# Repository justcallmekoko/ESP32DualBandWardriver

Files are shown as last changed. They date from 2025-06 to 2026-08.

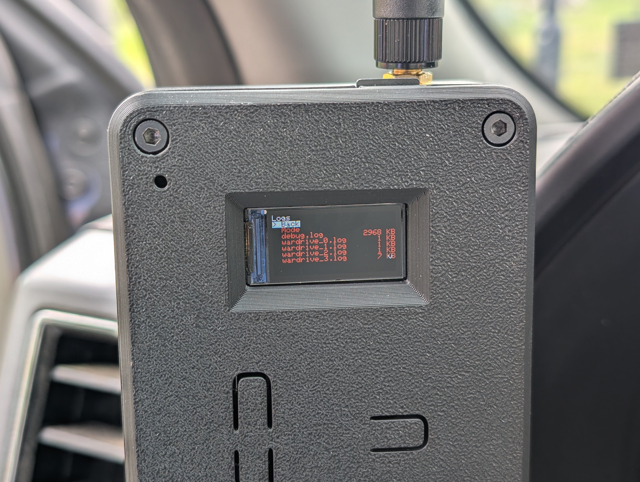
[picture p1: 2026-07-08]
docs/images/FileScreen.jpg

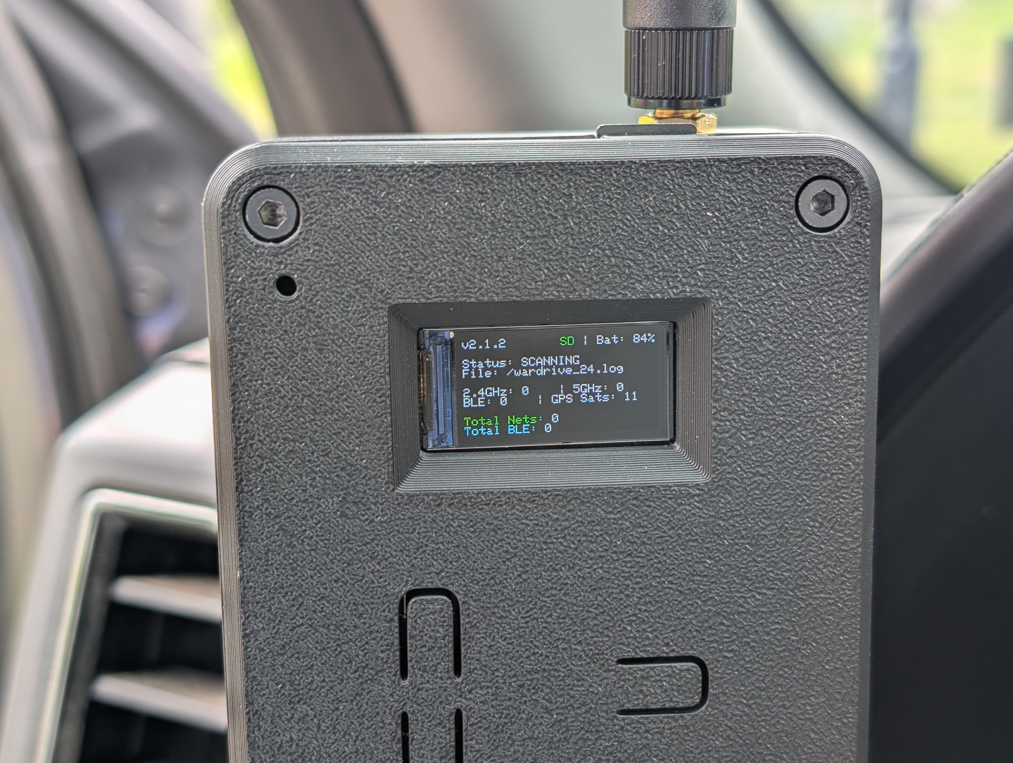
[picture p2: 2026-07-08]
docs/images/OriginalScreen2.jpg

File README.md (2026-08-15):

# ESP32 Dual Band Wardriver
Based on the ESP32-C5-DevKitC-1 v1.2, the ESP32 Dual Band Wardriver offers wardriving capabilities for 2.4GHz and 5GHz WiFi as well as BLE.
Logs are formatted for WiGLE and saved to SD card.

## Table of Contents
- [Leaderboards](#leaderboards)
- [Connections](#connections)
    - [Display](#display)
    - [GPS](#gps)
    - [SD Card](#sd-card)
    - [Battery Fuel Gauge](#battery-fuel-gauge)
    - [Activity LED](#activity-led)
    - [User Buttons](#user-buttons)
- [Install Firmware](#install-firmware)
- [Update Firmware](#update-firmware)
    - [Browser Installer (Recommended)](#browser-installer-recommended)
    - [SD Card Update](#sd-card-update)
- [Usage](#usage)
    - [Booting](#booting)
    - [Initial Setup](#initial-setup)
    - [Webserver Usage](#webserver-usage)
    - [Display Screens](#display-screens)
    - [Buttons](#buttons)
    - [Uploads](#uploads)
    - [Dock Mode](#dock-mode)
    - [Geofence Zones](#geofence-zones)
    - [SSID Exclusions](#ssid-exclusions)
    - [Debug Logging](#debug-logging)
- [Modes](#modes)

## Leaderboards
Join **#wardriving** on [WiGLE](https://wigle.net/stats#groupstats) and **KokosStripClub (invite code: _mN01r0TAS8q)** on [WDGWars](https://wdgwars.pl) to have a little competitive fun with the art of wardriving.

## Connections
**IMPORTANT: If you are using the ESP32-C5-DevKitC-1 with the JCMK C5 Wardriver host board or you are powering your DevKit via the 3V3 pin, you must remove the [3V3 jumper](https://docs.espressif.com/projects/esp-dev-kits/en/latest/esp32c5/esp32-c5-devkitc-1/user_guide.html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) from the DevKit or your device will not power properly.**

### [Display](https://a.co/d/dO8M3Ec)
| ESP32-C5 | Display |
| --- | --- |
| `3V3` | `VCC` |
| `GND` | `GND` |
| `GPIO6`  | `SCK` |
| `GPIO7`  | `MOSI`  |
| `GPIO23` | `CS` |
| `GPIO24` | `DC` |
| `GPIO27` | `BL` |
| `RST` | `RST` |

### [GPS](https://a.co/d/hIqIitg)
| ESP32-C5 | GPS |
| --- | ----- |
| `3V3` | `VCC` |
| `GND` | `GND` |
| `GPIO13` | `RX`  |
| `GPIO14` | `TX`  |

> **Tip:** The GPS module's ceramic patch antenna should be oriented face-up toward the sky for best signal. In the JCMK host board case the antenna mounts vertically by default — relocating it to the top of the enclosure significantly improves acquisition time.

### [SD Card](https://www.sparkfun.com/sparkfun-microsd-transflash-breakout.html)
| ESP32-C5 | SD |
| --- | --- |
| `3V3` | `VCC`  |
| `GND` | `GND`  |
| `GPIO6`  | `SCK`  |
| `GPIO2`  | `MISO` |
| `GPIO7`  | `MOSI` |
| `GPIO10` | `CS` |

### [Battery Fuel Gauge](https://www.adafruit.com/product/5580)
| Board | ESP32-C5 | Pin |
| --- | --- | ----- |
| | `GPIO4`  | `SCL` |
| | `GPIO5`  | `SDA` |
| | `3V3` | `VCC` |
| | `GND` | `GND` |
| `Battery +` | | `BAT` |

### Activity LED
| ESP32-C5 | LED |
| --- | --- |
| `GPIO28` | `+` |
| `GND` | `-` |

### User Buttons
The User Buttons require pull-down resistors.
| ESP32-C5 | Button |
| --- | --- |
| `GPIO8`  | `DOWN` |
| `GPIO9`  | `UP` |
| `GPIO15` | `SELECT` |

## Install Firmware

The [C5 Wardriver Installer](https://justcallmekoko.github.io/C5WardriverInstaller/) is the default and recommended method for installing firmware. It runs in a Chromium-based browser with Web Serial support, such as Google Chrome or Microsoft Edge.

1. Connect the ESP32-C5 DevKit to your computer with a USB data cable.
2. Open the [C5 Wardriver Installer](https://justcallmekoko.github.io/C5WardriverInstaller/).
3. Select the desired hardware and firmware version from the catalog.
4. Leave **Clean / first install** selected for a new device or a device previously running different firmware.
5. Read and acknowledge the erase warning, then select **Flash firmware** and choose the ESP32-C5 serial device.
6. Keep the device connected until the installer reports that flashing is complete, then power-cycle it.

**Clean / first install** erases the device and writes the complete compatible flash layout, including the bootloader, partition table, OTA data, and application. This is required when the existing flash layout is unknown or incompatible.

## Update Firmware

### Browser Installer (Recommended)

Use the [C5 Wardriver Installer](https://justcallmekoko.github.io/C5WardriverInstaller/) for normal firmware updates:

1. Connect the ESP32-C5 DevKit to your computer with a USB data cable.
2. Select the desired catalog firmware.
3. Select **Update / preserve settings** when the device already has a compatible C5 Wardriver flash layout.
4. Select **Flash firmware**, choose the ESP32-C5 serial device, and wait for completion before power-cycling.

Update mode preserves settings and writes the application to `app0` before updating OTA selection so the new firmware boots. If the device is factory-fresh, has an unknown partition layout, or does not boot after an update, repeat the process with **Clean / first install**.

### SD Card Update

SD card updates remain supported when a browser and direct USB connection are not convenient. The firmware checks the SD card root at every boot for a new `.bin` file and automatically installs it when found.

1. Download the latest firmware from [Releases](../../releases)
2. Place the `.bin` file on the root of your SD card
3. Install the SD card into the C5 Wardriver
4. Boot the C5 Wardriver and allow the automatic update process to execute

## Usage

### Booting
When powered on, the C5 Wardriver attempts to connect to WiFi using saved credentials. If no credentials are saved or the network is unavailable, it starts its own access point named `c5wardriver` (password: `c5wardriver`). The AP remains active for 60 seconds if no clients connect, or until all clients disconnect.

If the device connects to a saved WiFi network, the web UI remains available indefinitely — it will stay connected until the network disappears. You can skip the admin phase entirely by holding `SELECT` when the boot logo appears.

### Initial Setup
On first boot, connect to the `c5wardriver` access point and navigate to `http://192.168.4.1`. From the web UI you can configure:

- **WiFi SSID / Password** — network to connect at boot for web UI access
- **WiGLE API credentials** — for direct log upload to WiGLE
- **WDG Wars API key** — for direct log upload to WDGWars
- **Trigger SSID / Password** — network that triggers dock mode (see [Dock Mode](#dock-mode))
- **Admin Password** — enables Basic Auth on the web UI
- **SSID Exclusions** — SSIDs to never log
- **Geofence Zones** — zones where wardriving pauses
- **SD Debug Log** — enable to write all log entries to `/debug.log` on the SD card

### Webserver Usage
At every boot, if connected to a saved WiFi network, the device IP is shown on the display. Navigate to that IP from any device on the same network to access the web UI. From here you can download log files, upload to WiGLE or WDGWars, and reconfigure all settings.

A live log viewer is available at `http://<device-ip>/log` — auto-refreshes every 5 seconds and shows the last 100 log entries.

### Display Screens
Cycle between screens using the `UP` and `DOWN` buttons.

**Screen 1 — Stats (default)**
Large-format wardriving stats: GPS satellite count and lock status, battery percentage, scan status, current session 2.4GHz / 5GHz / BLE counts, running totals, and active geofence zone name.

**Screen 2 — Detail**
Original stats display: firmware version, SD status, battery, scan status, log file name, per-band counts, GPS satellites, and running totals.

**Screen 3 — Incognito**
5-second countdown then backlight off. Press any button to exit.

### Buttons
| Button | Function |
| --- | --- |
| `UP` | Cycle display mode forward |
| `DOWN` | Cycle display mode backward |
| `SELECT` | Hold at boot logo to skip admin phase |

### Uploads
Log files can be uploaded to WiGLE and WDGWars directly from the web UI or automatically via dock mode. Select a log file from the file list and choose Upload — options are WiGLE, WDGWars, or Both.

Sidecar files (`.wigle` / `.wdg`) are created after successful uploads to prevent duplicate uploads across reboots.

### Dock Mode
Dock mode automates log uploads when the wardriver detects a configured trigger SSID.

**How it works:**
1. While wardriving or in standby, the device passively scans for the trigger SSID every 30 seconds
2. When detected, it connects and uploads all pending log files (files without upload sidecars)
3. It monitors for the trigger SSID to disappear, then resumes wardriving automatically

**Two-tier operation:**
- **Tier 1 (no GPS fix):** Connects and serves the web UI only — no upload triggered
- **Tier 2 (GPS fix + SD card):** Full dock mode — uploads all pending logs to WiGLE and WDGWars

Tier 1 automatically upgrades to Tier 2 if a GPS fix is acquired while docked.

Configure the trigger SSID and password in the web UI under **Dock Mode**. The trigger SSID is separate from the boot WiFi network.

### Geofence Zones
Up to 5 geofence zones can be configured with a label, latitude/longitude, and radius (0.10 to 1.00 miles). When the wardriver enters a geofence zone, wardriving pauses and the zone name is shown on the display. Wardriving resumes automatically when the zone is exited.

Zones are configured from the web UI under **Geofences**.

### SSID Exclusions
Up to 10 SSIDs can be added to the exclusion list. Networks matching an excluded SSID are never logged regardless of location. Useful for filtering out your own networks or known networks you don't want to record.

Configure from the web UI under **SSID Exclusions**.

### Debug Logging
Enable **SD Debug Log** in the web UI Admin section to write all log entries to `/debug.log` on the SD card. Useful for diagnosing issues in the field without a serial connection. The debug log is available for download from the web UI file list but is excluded from upload queues.

## Modes
The C5 Wardriver supports multiple ESP32 modules operating as collection nodes reporting to a single Core device. Nodes and Cores communicate over-the-air within typical WiFi range.

**When configuring device mode from the web UI, the mode persists across reboots. When selecting mode from the on-device menu, it is temporary and resets on next boot.**

### Solo Mode
Standalone operation. Requires SD card, GPS module, and GPS fix. Logs directly to SD and supports direct upload to WiGLE and WDGWars.

### Node Mode
Collects wardriving data and sends it to a Core device. Does not require SD card or GPS.

### Core Mode
Receives data from Nodes, pairs it with GPS location data, and saves consolidated log files to SD. Requires SD card and GPS. Does not collect wardriving data itself. Supports direct upload to WiGLE and WDGWars.

### Encryption
Node-to-Core communications can be encrypted. Enable via the web UI. When encryption is enabled, a maximum of 6 nodes can operate simultaneously due to memory constraints. Without encryption, the number of nodes is theoretically unlimited.

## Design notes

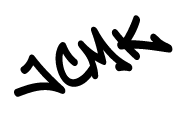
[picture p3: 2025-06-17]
images/jcmk.png

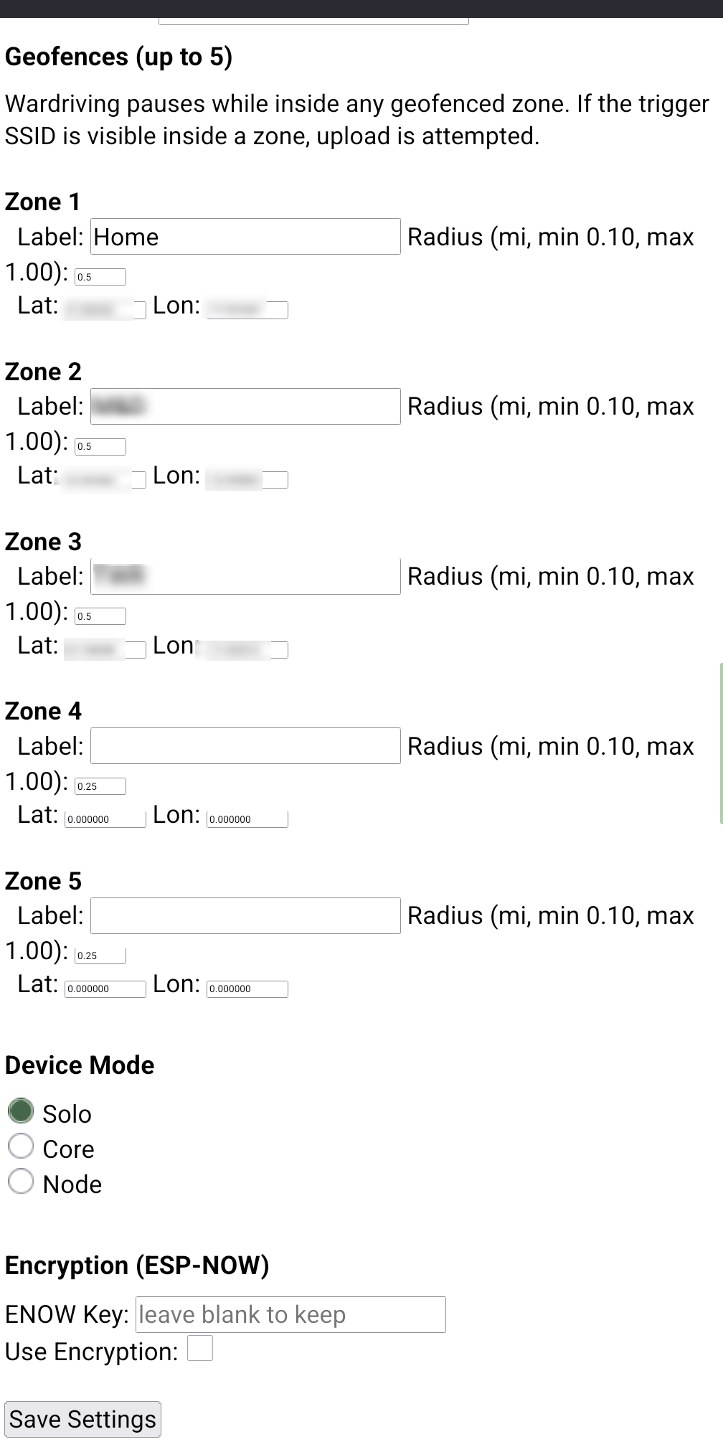
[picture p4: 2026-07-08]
docs/images/WebGeofenceScreen.png

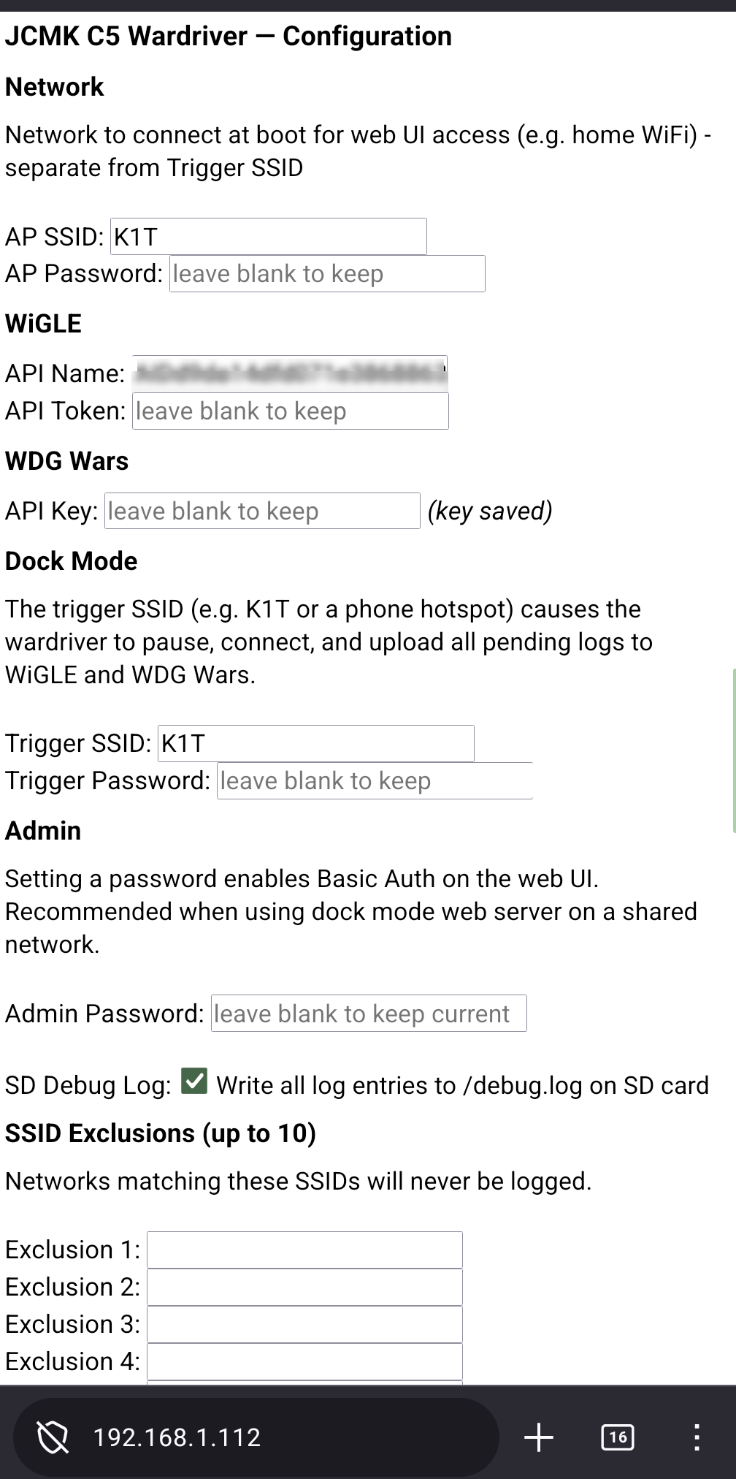
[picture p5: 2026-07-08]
docs/images/WebConfigScreen.png

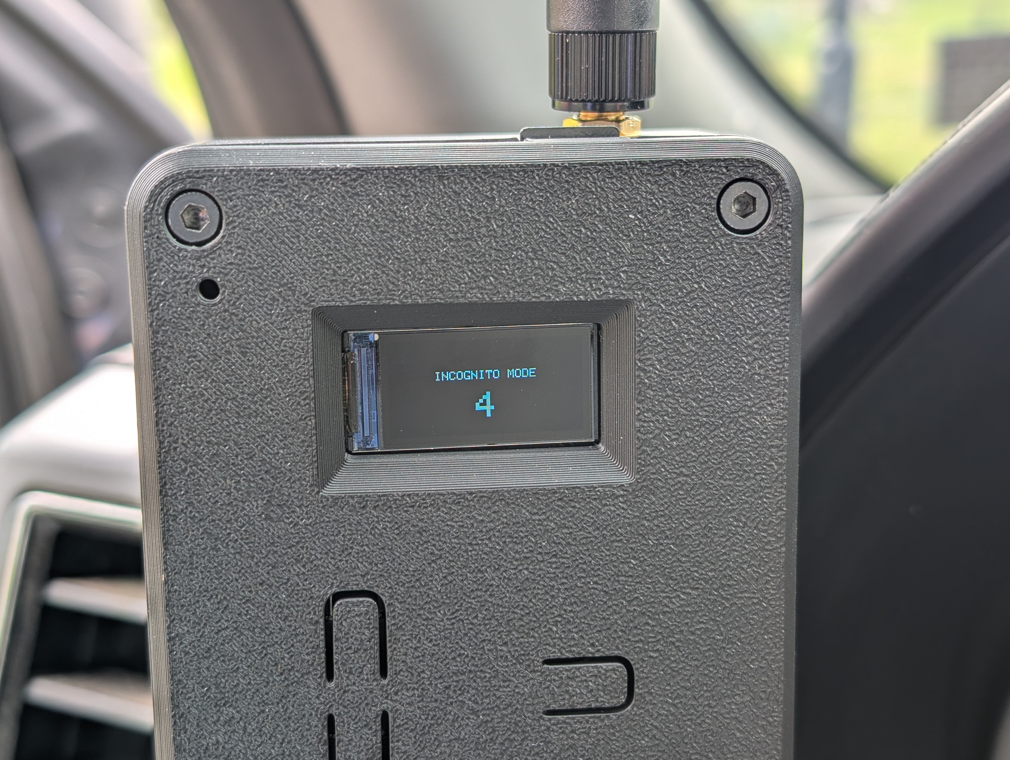
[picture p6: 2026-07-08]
docs/images/IgcognitoScreen.jpg

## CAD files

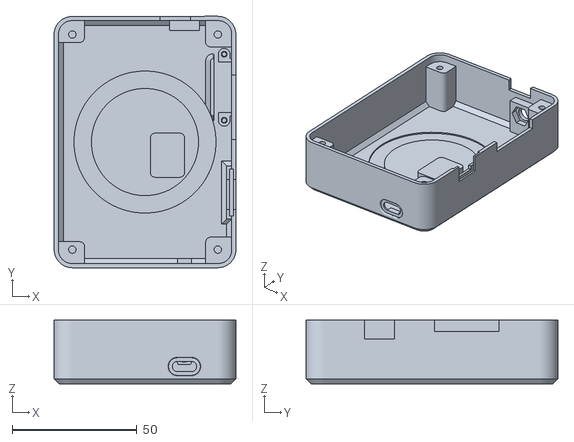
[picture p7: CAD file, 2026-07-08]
mechanical/printfiles/STL/Main Body.stl
73.1 x 101.0 x 25.6

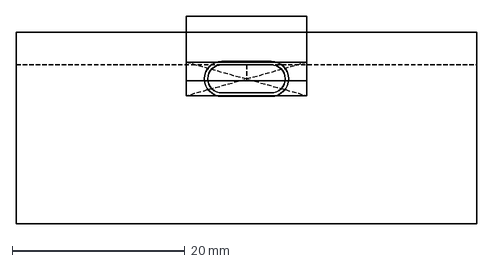
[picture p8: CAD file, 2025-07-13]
mechanical/design/USB-C.dxf
53.3 x 24.0 mm

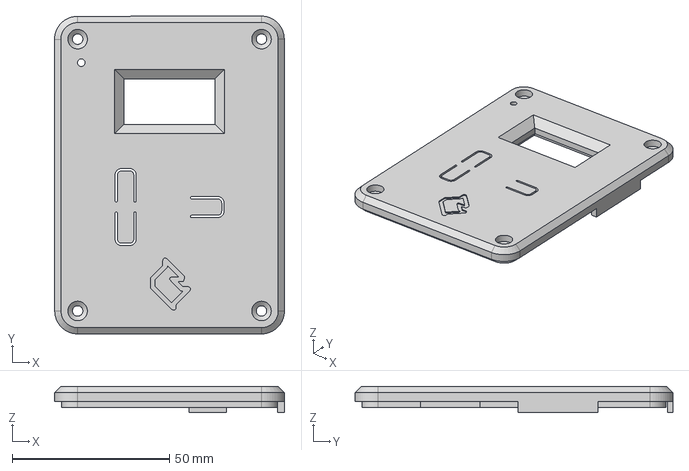
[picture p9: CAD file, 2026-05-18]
mechanical/printfiles/STEP/JCMK C5 Wardriver Faceplate (External Antenna)(FDM).step
73.1 x 101.0 x 8.40 mm

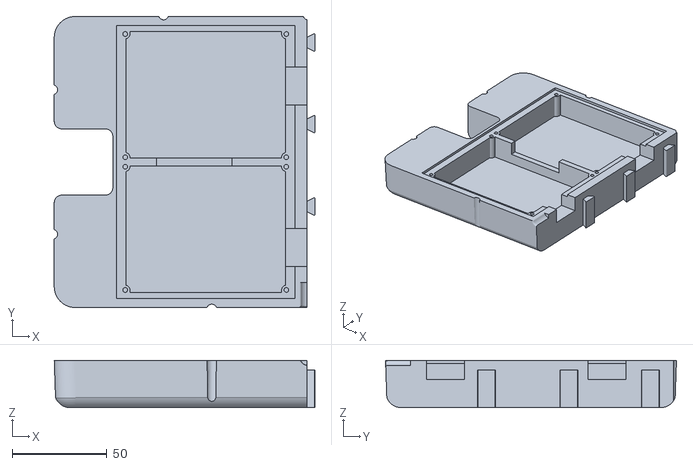
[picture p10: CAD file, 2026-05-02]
mechanical/printfiles/STL/Pelican1170/Cluster Insert (Left).stl
137.5 x 153.5 x 25.0

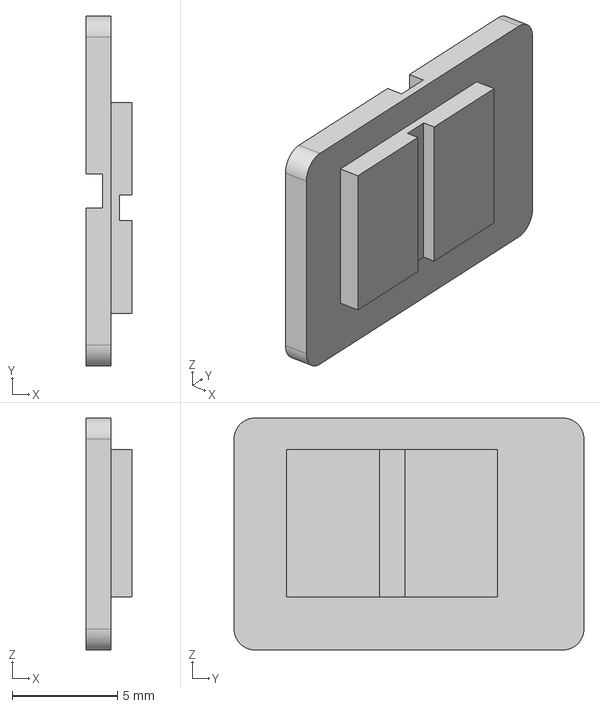
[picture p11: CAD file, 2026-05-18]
mechanical/printfiles/STEP/JCMK C5 Wardriver Power Switch(External Antenna)(FDM).step
2.20 x 16.6 x 11.0 mm

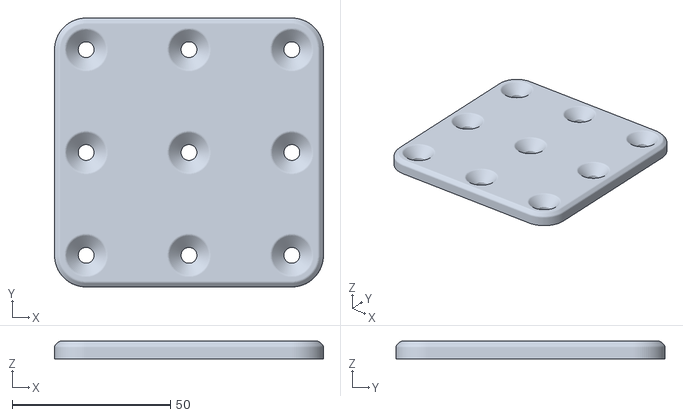
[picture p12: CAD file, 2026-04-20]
mechanical/printfiles/STL/Antenna Marking Tool.stl
85.0 x 85.0 x 5.56

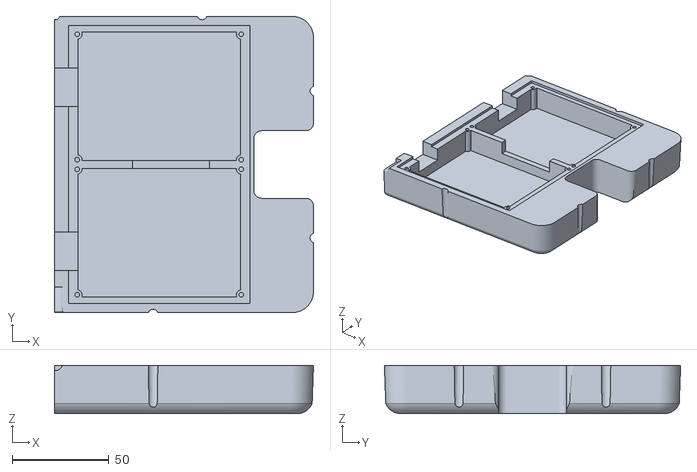
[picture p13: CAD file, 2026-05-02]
mechanical/printfiles/STL/Pelican1170/Cluster Insert (Right).stl
134.2 x 153.5 x 25.0

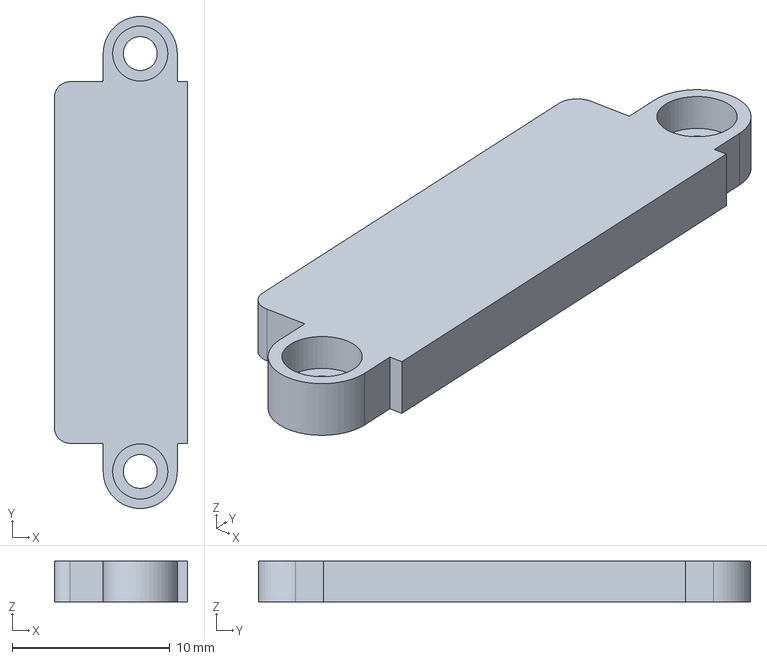
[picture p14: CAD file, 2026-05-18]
mechanical/printfiles/STEP/JCMK C5 Wardriver Antenna Cover(External Antenna)(FDM).step
8.46 x 31.2 x 2.60 mm

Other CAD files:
mechanical/printfiles/STEP/JCMK C5 Wardriver Main Body(External Antenna)(FDM).step
mechanical/printfiles/STL/GPS Antenna Lid.stl
mechanical/printfiles/STL/Faceplate.stl
mechanical/printfiles/STL/Switch.stl

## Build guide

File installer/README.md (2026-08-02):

# C5 Wardriver installer manifest

`targets.json` is the C5 installer identity registry. `tools/installer_manifest.py` creates release assets only from Arduino's expanded esptool upload recipe or concrete `flash_args`; if the build provides neither, generation fails rather than guessing flash geometry. Segment sources must remain inside the build directory, except for Arduino ESP32 core's exact `tools/partitions/boot_app0.bin` OTA seed.

Pull requests rebuild and upload the complete bundle as a short-lived review artifact, exercising the same build and manifest-generation path without touching a release. On publication of a non-prerelease release, the workflow rebuilds the tagged source, validates the firmware tag against `src/configs.h`, hashes the generated segments, and attaches an additive `firmware-manifest.json` plus uniquely named binary assets. Existing draft-release generation and its three existing binaries are unchanged.

No manifest is attached to old releases or drafts. The installer must therefore reject them until a release has completed this authoritative workflow.

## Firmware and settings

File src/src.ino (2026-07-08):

#include "configs.h"
#include "BatteryInterface.h"
#include "Buffer.h"
#include "settings.h"
#include "display.h"
#include "GpsInterface.h"
#include "SDInterface.h"
#include "Switches.h"
#include "WiFiOps.h"
#include "utils.h"
#include "ui.h"
#include "logger.h"

Buffer buffer;
Settings settings;
GpsInterface gps;
BatteryInterface battery;
WiFiOps wifi_ops;
Utils utils;
UI ui_obj;
bool g_force_display_redraw = false;

SPIClass sharedSPI(SPI);
Display display = Display(&sharedSPI, TFT_CS, TFT_DC, TFT_RST);
SDInterface sd_obj = SDInterface(&sharedSPI, SD_CS);

Switches u_btn = Switches(U_BTN, 1000, U_PULL);
Switches d_btn = Switches(D_BTN, 1000, D_PULL);
Switches c_btn = Switches(C_BTN, 1000, C_PULL);

void setup() {
  Serial.begin(115200);

  while (!Serial)
    delay(10);

  // Do SPI stuff first
  sharedSPI.begin(SPI_SCK, SPI_MISO, SPI_MOSI);

  // Give SPI some time I guess
  delay(100);

  // Init the display before SD
  display.begin();

  // Give SD some time
  delay(100);

  // Show us IDF information
  Logger::log(STD_MSG, "ESP-IDF version is: " + String(esp_get_idf_version()));

  pinMode(LED_PIN, OUTPUT);

  digitalWrite(LED_PIN, LOW);

  // Load settings
  settings.begin();

  if (settings.getSettingType(SETTING_SANITY) == "") {
    Logger::log(WARN_MSG, "Current settings format not supported. Installing new default settings...");
    settings.createDefaultSettings(SPIFFS);
  }
  else {
    Logger::log(GUD_MSG, "Current settings format supported");
  }

  // Init our buffer for writing logs
  buffer = Buffer();

  // Init SD Card
  if(!sd_obj.initSD())
    Logger::log(WARN_MSG, "SD Card NOT Supported");

  // Check for firmware updates now
  Logger::log(STD_MSG, "Checking for firmware updates...");
  sd_obj.runUpdate();

  // Enable SD debug logging if setting is on
  Logger::enableSDLog(settings.loadSetting<bool>(DEBUG_LOG_NAME));

  // Init battery
  battery.RunSetup();
  battery.battery_level = battery.getBatteryLevel();

  // Init GPS
  gps.begin();

  ui_obj.begin();

  // Init wifi and bluetooth
  wifi_ops.begin(c_btn.justPressed());

  // Init UI
  ui_obj.begin();

  settings.printJsonSettings(settings.getSettingsString());

  Logger::log(GUD_MSG, "Initialization complete!");
}

void loop() {
  // Take current time of this loop for functions
  uint32_t currentTime = millis();

  // Refresh all functions
  wifi_ops.main(currentTime, ui_obj.stat_display_mode == SD_FILES);
  settings.main(currentTime);
  battery.main(currentTime);
  gps.main();
  sd_obj.main();
  buffer.save();
  ui_obj.main(currentTime);

  // Solo or Core modes
  if ((gps.getFixStatus()) && (sd_obj.supported) && (ui_obj.stat_display_mode != SD_FILES))
    wifi_ops.setCurrentScanMode(WIFI_WARDRIVING);
  // Nodes
  else if ((wifi_ops.run_mode == NODE_MODE) && (wifi_ops.getNodeReady())) {
    wifi_ops.setCurrentScanMode(WIFI_WARDRIVING);
    digitalWrite(LED_PIN, HIGH);
  }
  else {
    wifi_ops.setCurrentScanMode(WIFI_STANDBY);
    if (wifi_ops.run_mode == NODE_MODE)
      digitalWrite(LED_PIN, LOW);
  }
}

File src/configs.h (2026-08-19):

#ifndef configs_h
#define configs_h

// Pins used:

/*
1 BTN
2 SPI
4 BAT I2C
5 BAT I2C
6 SPI
7 SPI
8 BTN
9 BTN
10 SD CS
13 GPS UART
14 GPS UART
23 TFT
24 TFT
27 TFT
28 ACT LED
*/

#define JCMK_HOST_BOARD

//// Firmware info stuff
#define FIRMWARE_VERSION "v2.3.2"
#define DEVICE_NAME      "JCMK C5 Wardriver"

//// Role stuff
#define SOLO
// #define CORE
// #define NODE

#if !defined(SOLO) && !defined(CORE) && !defined(NODE)
  #error "Define exactly one role: SOLO, CORE, or NODE"
#endif
#if defined(SOLO) && defined(CORE) && defined(NODE)
  #error "Define exactly one role: SOLO, CORE, or NODE"
#elif defined(SOLO) && defined(CORE)
  #error "Define exactly one role: SOLO, CORE, or NODE"
#elif defined(CORE) && defined(NODE)
  #error "Define exactly one role: SOLO, CORE, or NODE"
#elif defined(SOLO) && defined(NODE)
  #error "Define exactly one role: SOLO, CORE, or NODE"
#endif

#define SOLO_MODE 1
#define NODE_MODE 2
#define CORE_MODE 3

#define ENOW_KEY_MAX_LEN 32
#define ENOW_TEXT_MAX    200

//// BLE stuff
#define BLE_SCAN_DURATION   1 * 500 // 0.5 second


//// LED stuff
#define LED_PIN 28


//// Display stuff
#define ON  HIGH
#define OFF LOW

#define TFT_HEIGHT 80
#define TFT_WIDTH  160

#define TFT_SPI_SPEED 27000000

#define TFT_CS   23
#define TFT_DC   24
#define TFT_RST  -1
#define TOUCH_CS -1
#define TFT_MOSI 7
#define TFT_SCLK 6
#define TFT_BL   27


//// UI Stuff
#define UI_UPDATE_TIME 5 * 1000 // 1 second

#define U_BTN 9
#define D_BTN 8
#define C_BTN 1

#define C_PULL false
#define U_PULL false
#define D_PULL false

#define WEB_PAGE_TIMEOUT 60 * 1000 // 60 seconds
#define TIMER_UPDATE 1 * 1000 // 1 second
#define STATION_CONNECT_TIMEOUT 5 * 1000 // 5 seconds
#define WIFI_CONFIG "/settings.json"
#define LOG_FILE_NAME "wardrive"
#define SETTING_SANITY "t_ssid"

#define SMALL_CHAR_HEIGHT 8


//// Buffer stuff
#define BUF_SIZE 2 * 1024
#define SNAP_LEN 2324


//// Battery stuff
#define HAS_BATTERY
#define I2C_SCL 4
#define I2C_SDA 5


//// GPS stuff
#define GPS_SERIAL_INDEX 1
#define TX_TO_GPS 13
#define RX_TO_GPS 14


//// SD stuff
#define SPI_SCK  6
#define SPI_MISO 2
#define SPI_MOSI 7
#define SD_CS    10

#define UPDATE_KEY "UpdateFile"

//// Debug log
#define DEBUG_LOG_FILE "/debug.log"


//// Switch stuff



//// Device stuff
#define HAS_PSRAM
#define HAS_GPS
#define HAS_SD


////WiFi stuff
#define mac_history_len 200
#define CHANNEL_TIMER 80
#define SOLO_SCAN_MIN_DWELL_MS 80  // conservative probe-response window
#define SOLO_SCAN_MAX_DWELL_MS 120 // remain longer when an AP responds
#define SOLO_BONUS_CHANNEL_COUNT 8 // 20% bounded exploitation budget per base sweep
#define SOLO_BLE_INTERVAL_MS 4000
#if SOLO_SCAN_MIN_DWELL_MS > SOLO_SCAN_MAX_DWELL_MS
#error "SOLO active-scan minimum dwell cannot exceed maximum dwell"
#endif
#define LOG_ROLL_ENTRIES  10000  // start a new log file after this many entries


// ============================================================
// Chunk 1: Extended feature constants
// ============================================================

//// Geofence stuff
#define MAX_GEOFENCES         5

//// SSID Exclusion stuff
#define MAX_SSID_EXCLUSIONS   10

//// Dock mode stuff
#define DOCK_CONNECT_ATTEMPTS  3
#define DOCK_CONNECT_TIMEOUT   10 * 1000   // 10 seconds per attempt
#define DOCK_SCAN_INTERVAL     30 * 1000   // passive scan every 30s while docked
#define DOCK_DEPART_SCANS      2           // consecutive misses before resuming wardrive
#define DOCK_FAIL_DISPLAY_MS   20 * 1000   // show K1T failure message for 20s
#define STANDBY_SCAN_INTERVAL  30 * 1000   // scan for K1T every 30s while in standby (no GPS)

//// Settings JSON buffer — bumped from 2048 to handle 30 settings entries
#define SETTINGS_JSON_SIZE     4096

// ============================================================
// Chunk 6: Dock mode state constants
// ============================================================
#define DOCK_STATE_NONE       0  // wardriving normally
#define DOCK_STATE_CONNECTING 1  // attempting WiFi connect to trigger SSID
#define DOCK_STATE_UPLOADING  2  // uploading all pending log files
#define DOCK_STATE_MONITORING 3  // watching for trigger SSID departure
#define DOCK_STATE_FAILED     4  // connect failed, showing message before resume

#endif

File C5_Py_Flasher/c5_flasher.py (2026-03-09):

# === ESP32-C5 Auto Flasher Script By: AWOK ===

import sys
import subprocess
import os
import platform   # Placeholder for possible OS checks
import glob
import time
import shutil
import argparse

def version_tuple(v):
    return tuple(int(x) for x in v.split('.') if x.isdigit())
    
def ensure_esptool_version(min_version="5.0.1"):
    try:
        import esptool
        installed = esptool.__version__
    except Exception:
        installed = None

    if installed is None or version_tuple(installed) < version_tuple(min_version):
        print(f"Installing/upgrading esptool to >= {min_version} (current: {installed})")
        subprocess.check_call([
            sys.executable, "-m", "pip", "install",
            f"esptool>={min_version}", "--upgrade"
        ])

        # reload module after install
        import importlib
        import esptool
        importlib.reload(esptool)

    print(f"Using esptool version: {esptool.__version__}")

def ensure_package(pkg):
    try:
        __import__(pkg if pkg != 'gitpython' else 'git')
    except ImportError:
        print(f"Installing missing package: {pkg}")
        subprocess.check_call([sys.executable, '-m', 'pip', 'install', '--upgrade', pkg])

try:
    import serial.tools.list_ports
except ImportError:
    ensure_package('pyserial')
    
ensure_esptool_version("5.0.1")
import esptool

try:
    from colorama import Fore, Style
except ImportError:
    ensure_package('colorama')

# Dependency check and install if needed
REQUIRED_PACKAGES = [
    'pyserial',
    'esptool',
    'colorama'
]

def ensure_requirements():
    for pkg in REQUIRED_PACKAGES:
        ensure_package(pkg)
ensure_requirements()

# Finds the first file from a list of possible names in the bins folder
def find_file(name_options, bins_dir):
    for name in name_options:
        files = glob.glob(os.path.join(bins_dir, name))
        if files:
            return files[0]
    return None
    
def run_esptool(args, success_msg=None, fail_prefix="esptool failed"):
    """
    Runs esptool.main(args) but prevents esptool from terminating this script via sys.exit().
    Treats exit code 0 as success, non-zero as failure.
    """
    try:
        esptool.main(args)
        if success_msg:
            print(success_msg)
        return True
    except SystemExit as e:
        # esptool calls sys.exit(code). code==0 means success.
        code = e.code if isinstance(e.code, int) else 0
        if code == 0:
            if success_msg:
                print(success_msg)
            return True
        print(Fore.RED + f"{fail_prefix} (exit code {code})" + Style.RESET_ALL)
        return False
    except Exception as e:
        print(Fore.RED + f"{fail_prefix}: {e}" + Style.RESET_ALL)
        return False

def main():
    parser = argparse.ArgumentParser(description="ESP32-C5 Auto Flasher (bins subdir)")
    parser.parse_args()

    bins_dir = os.path.join(os.path.dirname(__file__), 'bins')
    if not os.path.isdir(bins_dir):
        print(Fore.RED + f"Bins directory not found: {bins_dir}\nPlease create a 'bins' folder with your .bin files." + Style.RESET_ALL)
        exit(1)

    # Logo and splash, both centered and purple
    terminal_width = shutil.get_terminal_size((100, 20)).columns
    def center(text): return text.center(terminal_width)
    logo_lines = [
        "                                            @@@@@@                              ",
        "                                @@@@@@@@  @@@@@ @@@@                            ",
        "                               @@@    @@@@@@@     @@@     @@@@@@@@              ",
        "                    @@@@@@@@@@@@@      @@@@@       @@@  @@@@    @@@             ",
        "                   @@@      @@@@@       @@@         @@@@@@       @@@            ",
        "                  @@@         @@@        @@         @@@@         @@@            ",
        "         @@@@@@@@@@@@          @@        @          @@@         @@@     @@      ",
        "        @@@     @@@@@           @@           @@@    @@          @@@@@@@@@@@@@@  ",
        "       @@@         @@@           @@          @@@               @@@@@        @@@@",
        "       @@@           @@                     @@@@              @@@            @@@",
        "      @@@@@            @@                   @@@@                             @@@",
        "   @@@@@@  @@                @@         @   @@@                            @@@@ ",
        "  @@@                         @@       @@         @                     @@@@@@  ",
        " @@@                           @@     @@@        @@            @@@@@@@@@@@@@@@  ",
        "@@@       @@@@      @          @@@@  @@@@@     @@@        @      @@@@  @@@ @@@  ",
        "@@@       @@@@@@@    @@@       @@@@@@@@@@@@@@@@@@@       @@        @@@ @@@      ",
        "@@@        @@@@@ @@@  @@@@@  @@@@ @@@@  @@@@@@@@@@      @@@@        @@@         ",
        "@@@@            @@@@@@@@@@@@@@@@  @@@   @@@ @@  @@@@@@@@@@@@         @@@        ",
        " @@@@          @@@@@@@@@@@@@@@@   @@@       @@   @@@@@@@@@@@@        @@@        ",
        "  @@@@@@     @@@@@   @@@     @@    @               @@  @@  @@@@    @@@@         ",
        "   @@@@@@@@@@@@@     @@@     @@                    @@  @@   @@@@@@@@@@@         ",
        "   @@@@@@@@@@@@      @@@     @@                   @@@  @     @@@@@@@@           ",
        "        @@  @@                                    @@@        @@  @@@            ",
        "        @   @@                                               @@  @@@            ",
        "           @@@                                                   @@@            ",
        "           @@@                                                                  ",
        ""
    ]
    splash_lines = [
        "--  ESP32 C5 Flasher --",
        "By AWOK",
        "Inspired from LordSkeletonMans ESP32 FZEasyFlasher",
        "Shout out to JCMK for the inspiration on setting up the C5",
        ""
    ]
    print(Fore.MAGENTA + "\n" + "\n".join(center(line) for line in logo_lines + splash_lines) + Style.RESET_ALL)

    # Wait for ESP32 device to show up as a new serial port
    existing_ports = set([port.device for port in serial.tools.list_ports.comports()])
    print(Fore.YELLOW + "Waiting for ESP32-C5 device to be connected..." + Style.RESET_ALL)
    while True:
        current_ports = set([port.device for port in serial.tools.list_ports.comports()])
        new_ports = current_ports - existing_ports
        if new_ports:
            serial_port = new_ports.pop()
            break
        time.sleep(0.5)
    print(Fore.GREEN + f"Detected ESP32-C5 on port: {serial_port}" + Style.RESET_ALL)

    # Find bin files for each firmware component
    bootloader = find_file(['bootloader.bin'], bins_dir)
    partitions = find_file(['partition-table.bin', 'partitions.bin'], bins_dir)
    ota_data = find_file(['ota_data_initial.bin'], bins_dir)
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

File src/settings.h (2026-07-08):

#pragma once

#ifndef Settings_h
#define Settings_h

#include "configs.h"
#include "logger.h"
#include "utils.h"

#include "SPIFFS.h"
#include <FS.h>
#include <ArduinoJson.h>

#define FORMAT_SPIFFS_IF_FAILED true

#define CLICK_NAME "Click"
#define ALARM_NAME "Alarm"
#define VIBE_NAME  "Vibration"
#define TIME_NAME  "Timestamp"
#define SEN_SUB    "Subghz Sens"
#define SEN_2G4    "2.4ghz Sens"
#define SEN_5G8    "5.8ghz Sens"
#define LOW_SENS   1
#define MED_SENS   2
#define HIGH_SENS  3

// ============================================================
// Chunk 1: New setting key names
// ============================================================
#define WDG_KEY_NAME       "wdg_key"   // WDG Wars API key (String)
#define TRIGGER_SSID_NAME  "t_ssid"    // Dock trigger SSID e.g. "K1T" (String)
#define TRIGGER_PASS_NAME  "t_pass"    // Dock trigger SSID password (String)
#define ADMIN_PASS_NAME    "a_pass"    // Basic Auth password for web UI (String)
#define DEBUG_LOG_NAME     "dbg_en"    // SD debug log enabled (bool)
// SSID exclusion list keys:  "sx_0" through "sx_9"   (String each)
// Geofence keys:             "geo_0" through "geo_4" (String, JSON encoded)
// Geofence JSON format: {"lat":0.000000,"lon":0.000000,"rad":0,"label":""}

class Settings {

  private:
    String json_settings_string;

  public:
    bool begin();

    template <typename T>
    T loadSetting(String name);

    template <typename T>
    T loadSettingMin(String name);

    template <typename T>
    T loadSettingMax(String name);

    template <typename T>
    T saveSetting(String key, bool value);

    template <typename T>
    T saveSetting(String key, int value, bool is_int = true);

    template <typename T>
    T saveSetting(String key, String value);

    bool toggleSetting(String key);
    String getSettingType(String key);
    String setting_index_to_name(int i);
    int getNumberSettings();

    String getSettingsString();
    bool createDefaultSettings(fs::FS &fs, bool spec = false, uint8_t index = 0, String typeStr = "bool", String name = "");
    void printJsonSettings(String json_string);
    void wipeSPIFFS();
    void main(uint32_t currentTime);
};

#endif

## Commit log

2025-06-10 Replace serial print with logger messages
    [BatteryInterface.cpp, SDInterface.cpp, configs.h]
2025-06-11 Fix Wigle header info
    [WiFiOps.cpp]
2025-06-12 Add display stuff but it doesn't work yet
    [SDInterface.cpp, WiFiOps.cpp, configs.h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]
2025-06-12 Add activity LED
2025-06-12 Fix BLE wigle format
    [WiFiOps.cpp]
2025-06-13 Update battery monitor pins
2025-06-16 Add SD update and buttons
2025-06-17 Add PCB silkscreen images
2025-06-17 Add user button connections
2025-07-13 UI modes, board config, file size, enclosure
    [Faceplate.stl, Main Body (SLS).stl, Main Body.stl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]
2025-07-14 Add button usage documentation
2025-07-17 Update battery fuel gauge pins
2025-07-17 Add battery fuel gauge documentation
2025-07-29 Update select button pin
2025-07-29 Add arduino-esp32 core install
2025-07-30 Fix battery gauge not returning value
    [BatteryInterface.cpp, WiFiOps.cpp]
2026-01-20 Create Main Body (External GPS Antenna).stl
    [Main Body (External GPS Antenna).stl]
2026-01-28 Update GPS antenna location
    [GPS Antenna Lid.stl, Main Body.stl]
2026-03-08 Add core framework for channel assignments
2026-03-08 Add timer to show node table
2026-04-20 Manually extract auth type
    [Antenna Marking Tool.stl, Main Body (SLS).stl]
2026-05-02 Add Pelican 1170 case insert
    [Cluster Insert (Left).stl, Cluster Insert (Right).stl]
2026-05-06 Update external GPS antenna enclosure
    [Main Body (External GPS Antenna).stl]
2026-05-18 Add STEP files for enclosure
    [JCMK C5 Wardriver Antenna Cover(External Antenna)(FDM).step, JCMK C5 Wardriver Faceplate (External Antenna)(FDM).step, JCMK C5 Wardriver Main Body(External Ant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]
2026-06-15 Fix exit SD menu display refresh
    [configs.h, ui.h]
2026-06-15 Upload all, fix display refresh
    [WiFiOps.cpp, WiFiOps.h, configs.h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]
2026-06-17 Fix some display artifacts
    [WiFiOps.cpp, WiFiOps.h]
2026-06-17 Update main body design file
    [Main Body (External GPS Antenna).stl, Main Body (SLS).stl, Main Body.stl]
2026-06-30 Fix trigger scanning while on menu
    [WiFiOps.cpp, WiFiOps.h, configs.h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]
2026-08-02 fix: expose Arduino CLI during setup step
2026-08-02 fix: allow Arduino core OTA seed segment
2026-08-03 fix: allow empty mobile geofences
    [WiFiOps.cpp]
2026-08-14 Correct C5 host board flashing guidance
2026-10-19 Pin Arduino CLI used by firmware CI
2026-10-19 Stabilize Arduino package index setup
2026-10-19 feat: expose core MAC in device interfaces
2026-10-30 Promote develop to main (#80)
    Promote the hardware-validated T-Dongle C5 integration, shared-SPI recovery, and Node-mode Wi-Fi counter fix.
